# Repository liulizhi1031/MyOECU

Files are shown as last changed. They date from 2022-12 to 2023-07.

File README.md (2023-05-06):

# 开源嵌入式计算单元

**MyO**pensource**E**mbedded**C**ompute**U**nit (**MyOECU**)

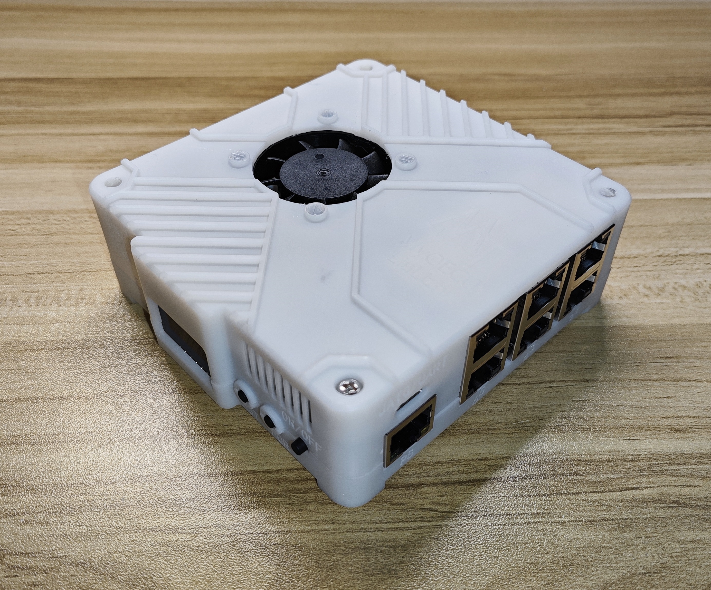
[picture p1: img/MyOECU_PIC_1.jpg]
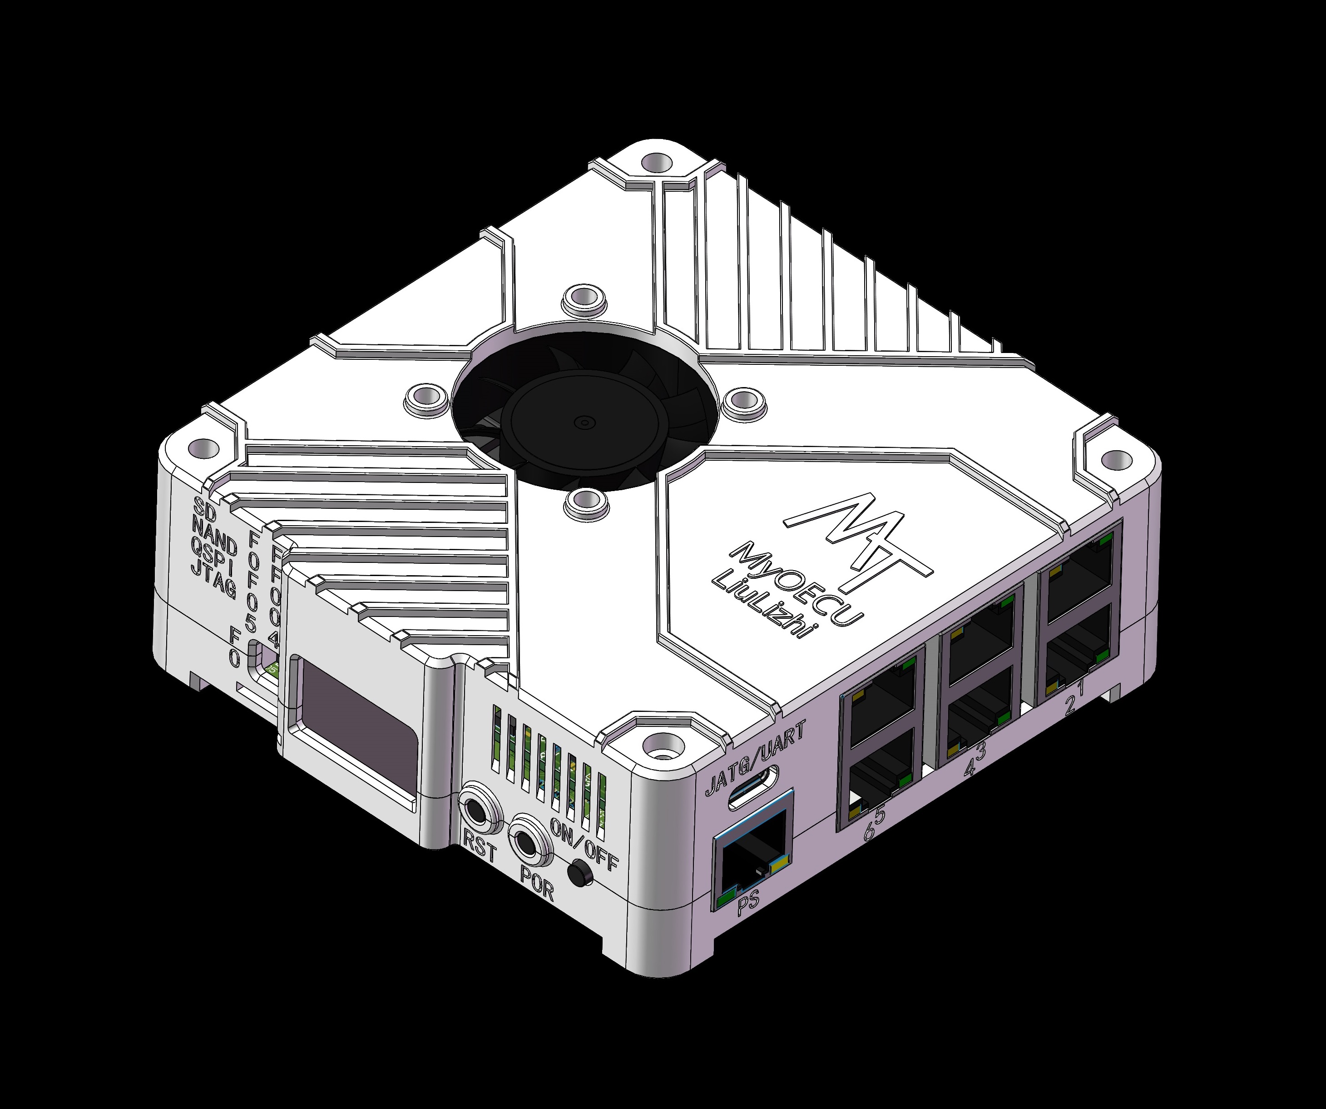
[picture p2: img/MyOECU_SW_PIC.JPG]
<div align="center">  

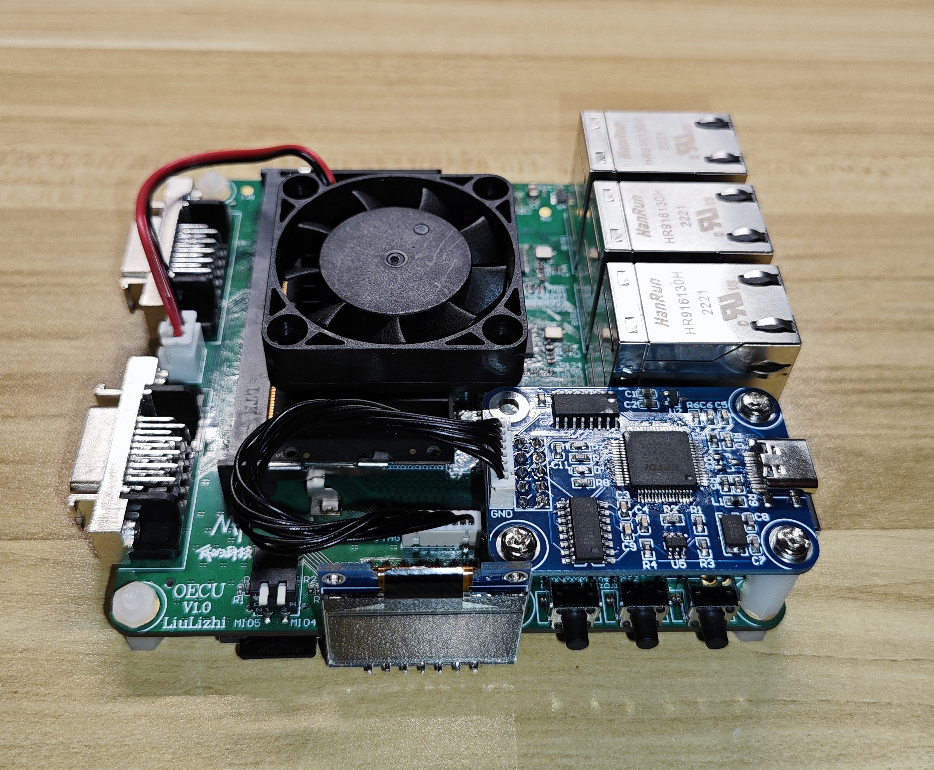
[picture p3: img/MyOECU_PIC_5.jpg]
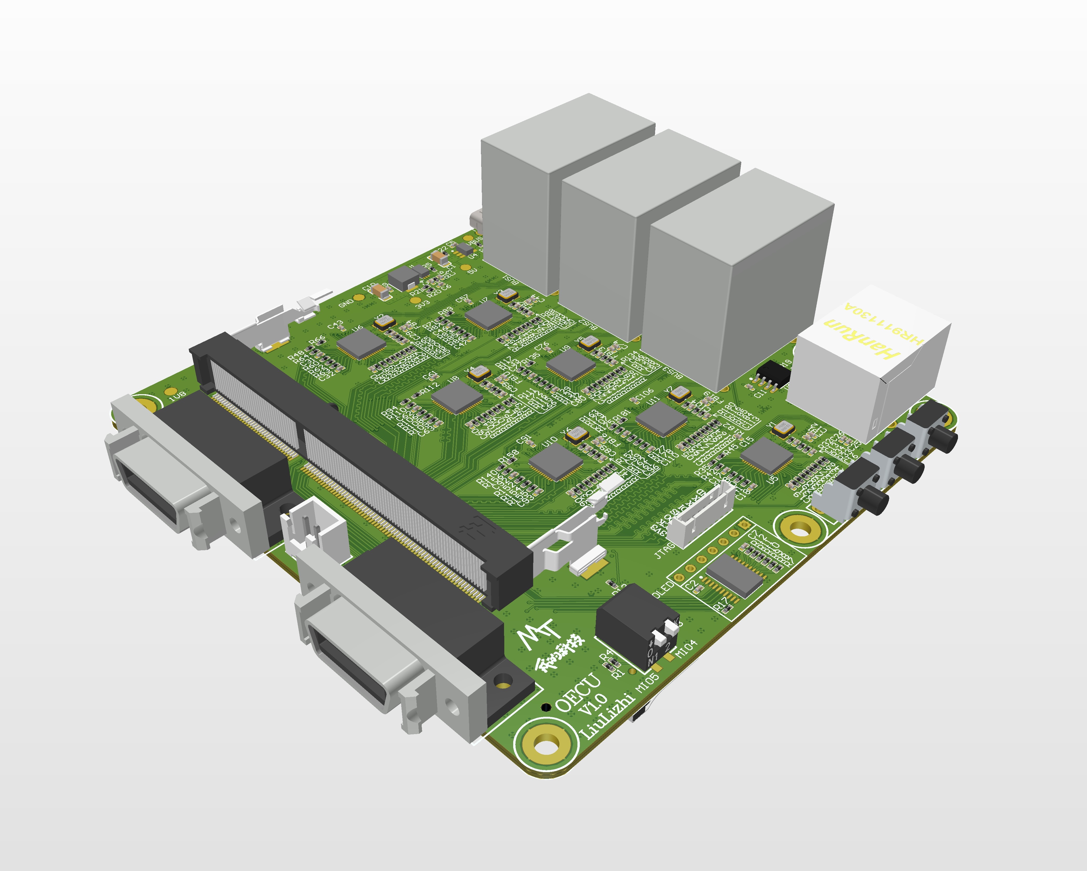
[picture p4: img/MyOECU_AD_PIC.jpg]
<div align="center"> 

<div align="left">

- ## 简介

	本项目是一种开源嵌入式计算单元原型机，主要用于构建分布式控制系统，充当核心计算角色或小型总线交换机。通过板载的三路双冗余千兆网络总线，本计算单元可以方便的与其他计算单元、传感器、交换机、作动器等实现互联互操作。使用基于PreemptRT的实时Linux操作系统或FreeRTOS，可快速实现应用软件开发。本计算单元适用于航空航天、工业控制、智能家居等诸多领域。

- ## 组成

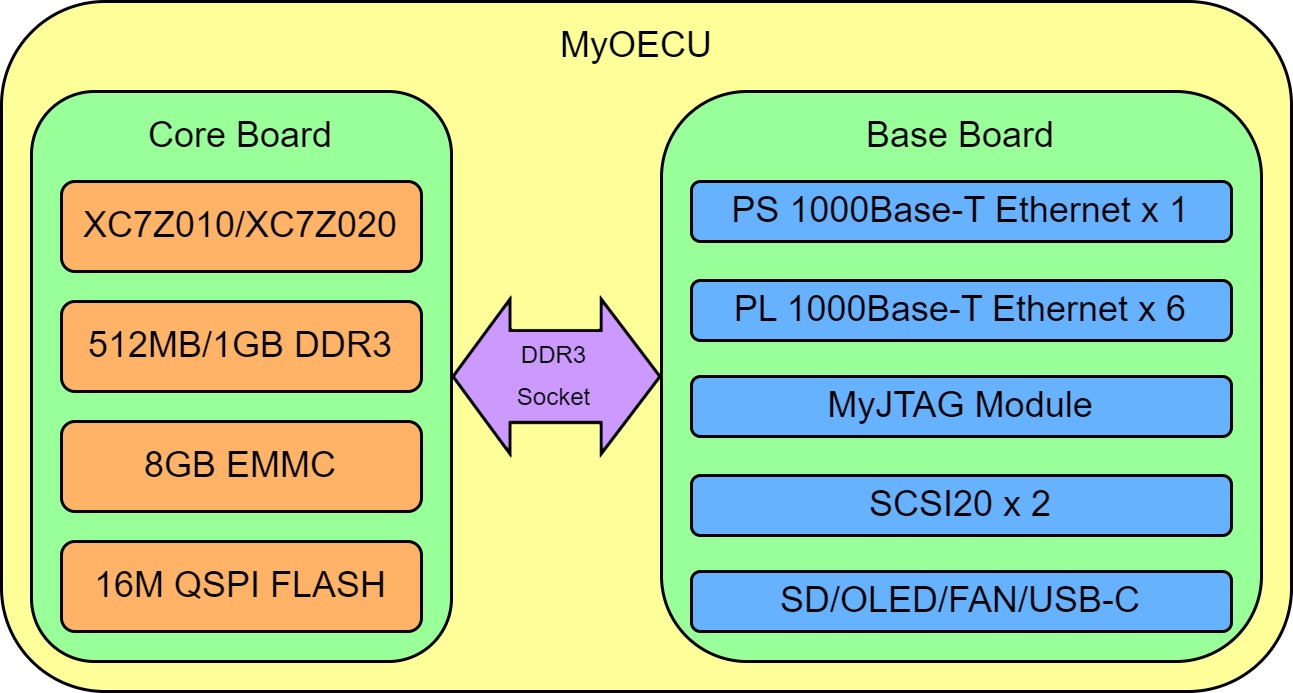
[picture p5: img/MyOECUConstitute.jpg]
MyOECUConstitute


1. 使用Zynq7010/7020作为主控制器，核心板通过DDR3插槽与底板相连；
2. 一路PS端千兆以太网接口；
3. 六路PL端千兆以太网接口，搭配FPGA软件组成三组双冗余高速总线或六组高速总线；
4. 预留MyJTAG模块接口，包含一路JTAG调试接口与一路串口，共用一个USB Type-C接口与调试机相连；
5. 主电源接口为USB Type-C接口，支持5V 3A输入，除此之外也可使用SCSI20扩展接口供电。主电源开关由负载开关组成，一键开关机；
6. 预留CAN总线接口、串口等IO资源，通过SCSI20接口与外部相连，预留SD卡接口，搭载0.96寸SPI接口OLED显示屏；
7. PCB尺寸为10cm*10cm，六层板；

- ## 分布式控制系统

分布式控制系统相比集中式控制系统拥有较多优势：

1. 采用模块化设计，方便对子模块进行快速调试、维护、更换、升级等操作
2. 更好的故障隔离能力，对于设计良好的分布式系统，部分子模块损坏并不会影响整个控制网络的基本运行
3. 可灵活进行系统的余度配置，有利于提高系统的可靠性
4. 通用设计的计算单元可快速构建不同功能模块，降低系统研发成本，加快系统研发进度
5. 单个功能模块功耗较低，有利于系统的热设计
6. 各功能模块分散布置，从而避免因局部机械失效导致的灾难性后果

- ## 应用示例

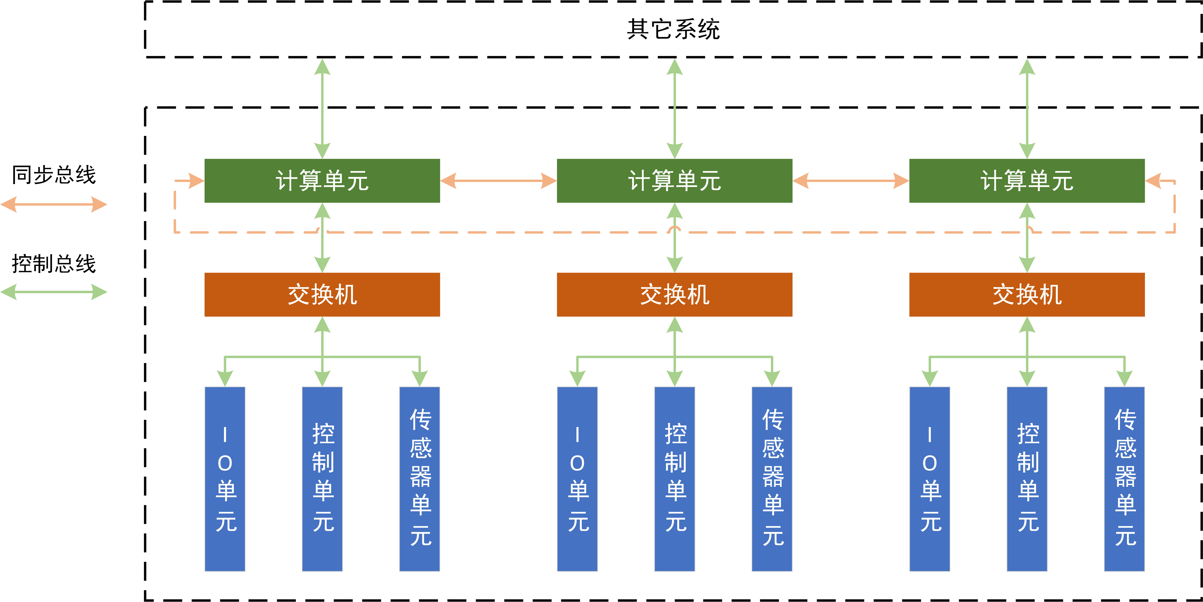
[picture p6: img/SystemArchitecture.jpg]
SystemArchitecture


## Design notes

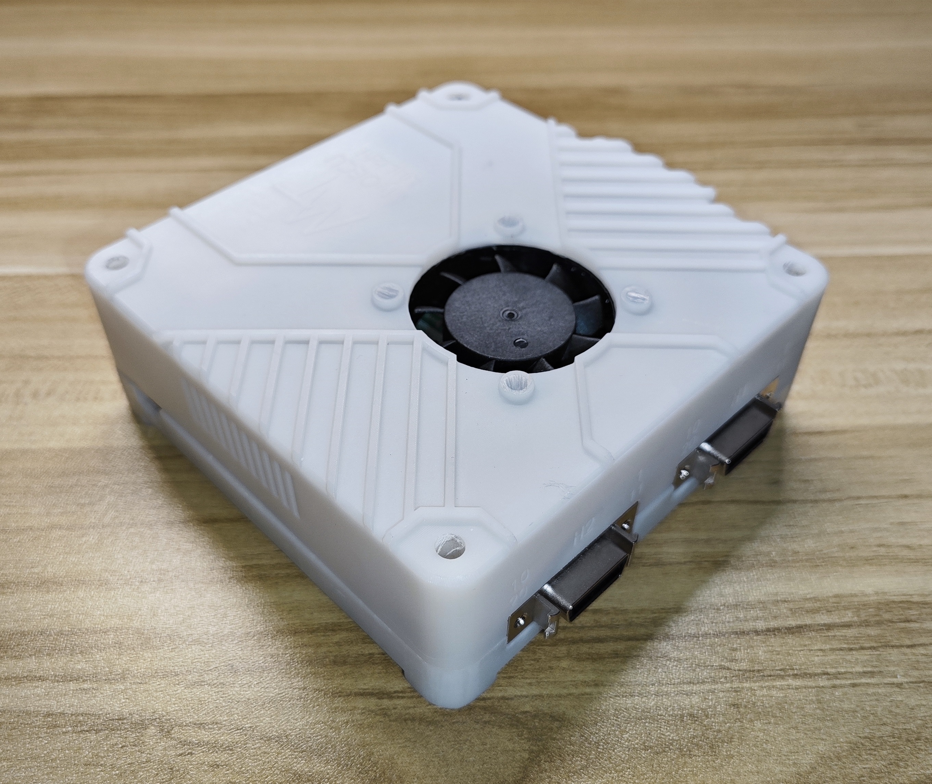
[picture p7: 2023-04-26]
img/MyOECU_PIC_3.jpg

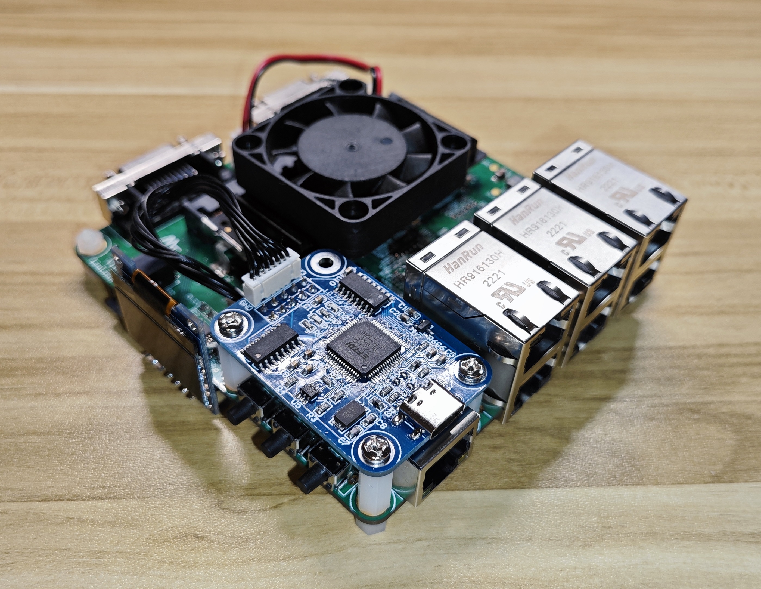
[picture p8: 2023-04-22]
img/MyOECU_PIC_4.jpg

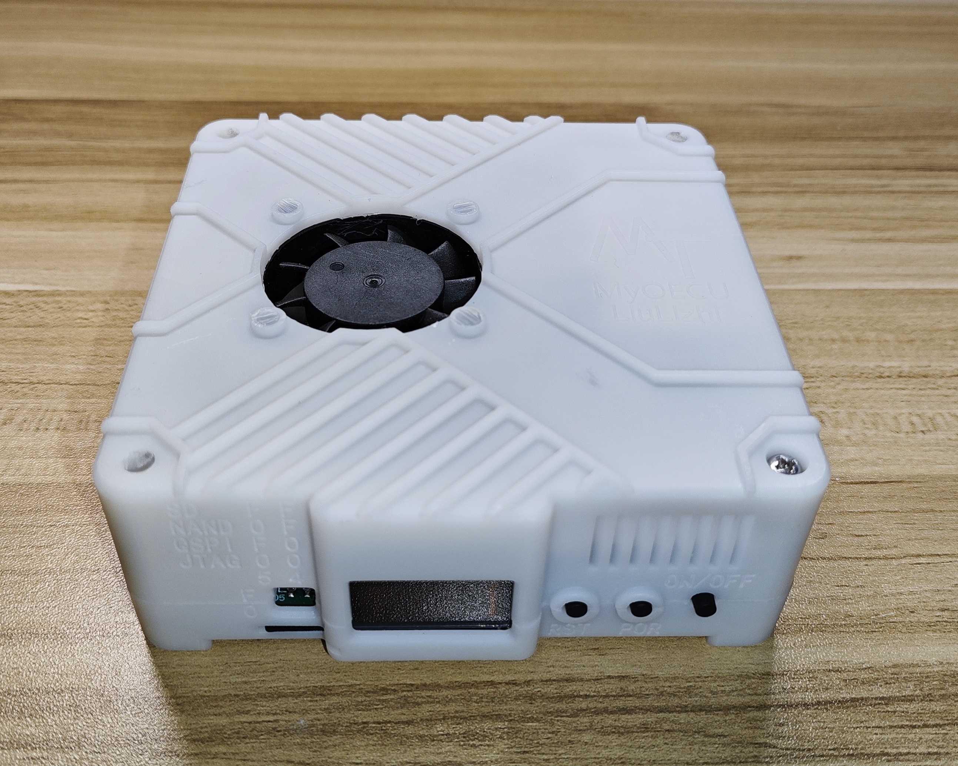
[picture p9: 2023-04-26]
img/MyOECU_PIC_2.jpg

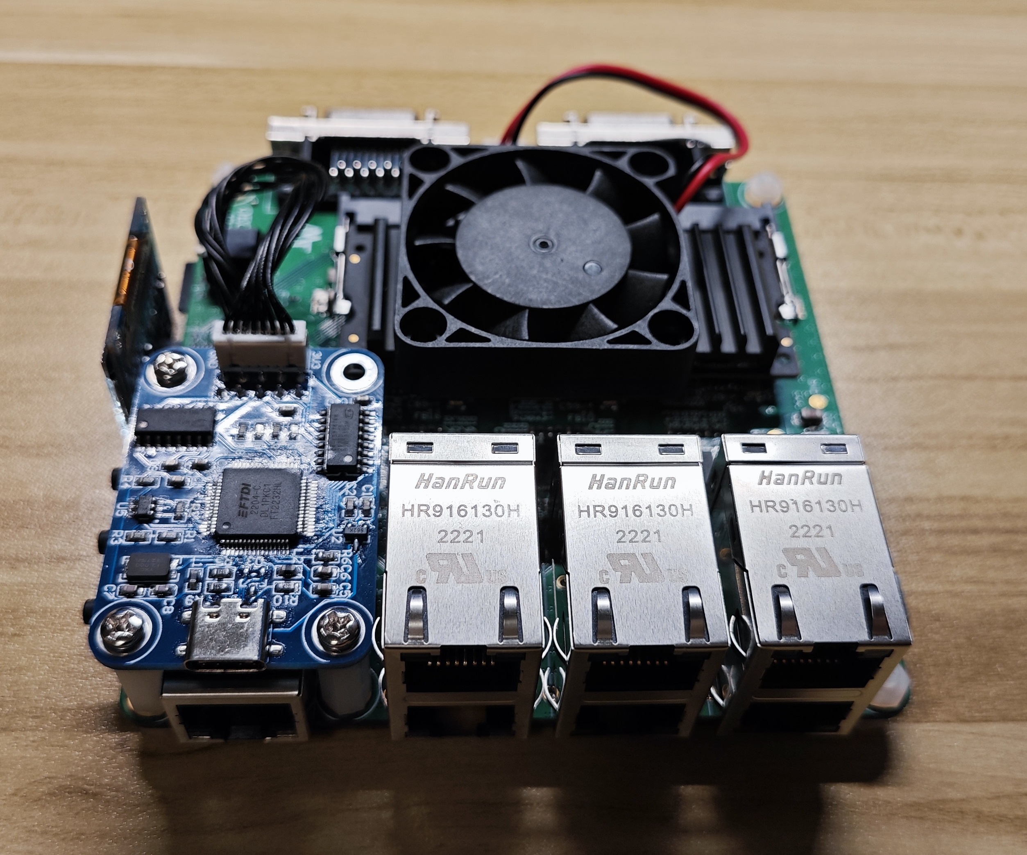
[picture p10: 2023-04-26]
img/MyOECU_PIC_6.jpg

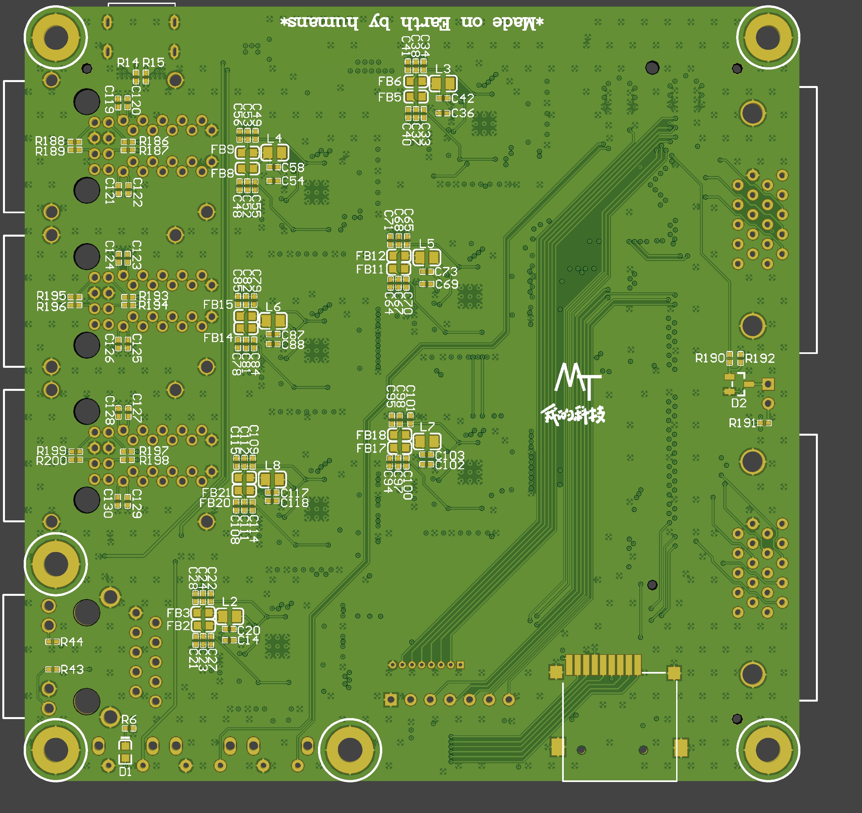
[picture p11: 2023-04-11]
3D_model/MyOECU/OECU_BASE_BUTTOM.jpg

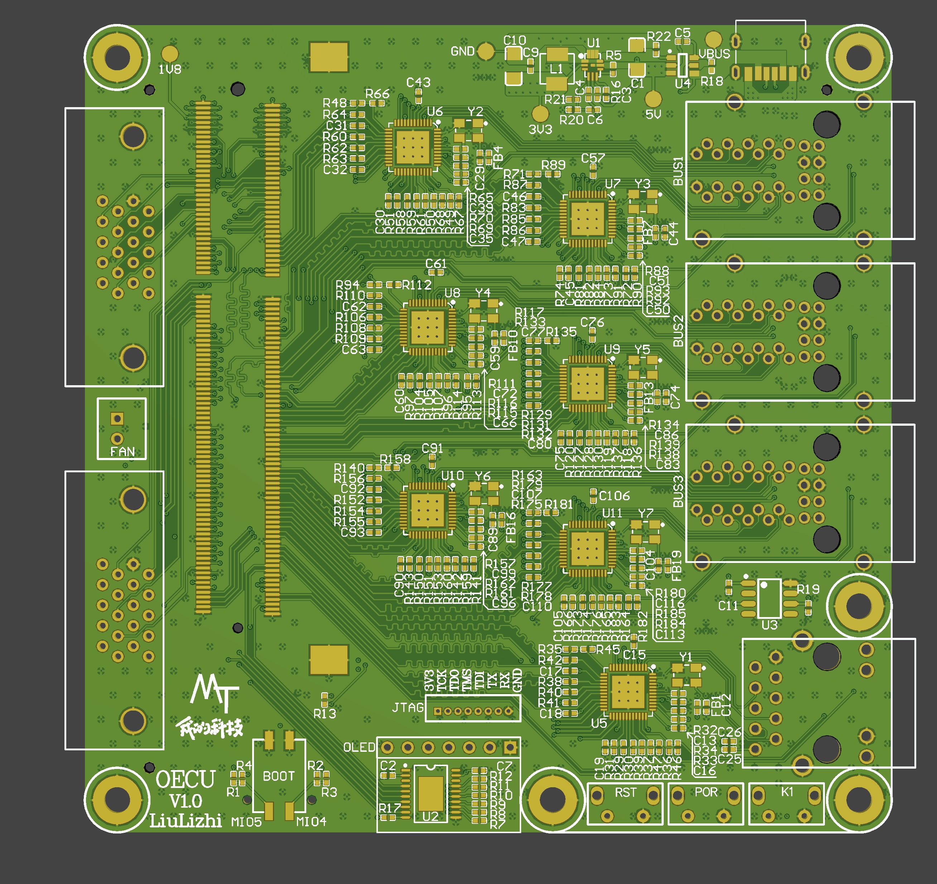
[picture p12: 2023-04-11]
3D_model/MyOECU/OECU_BASE_TOP.jpg

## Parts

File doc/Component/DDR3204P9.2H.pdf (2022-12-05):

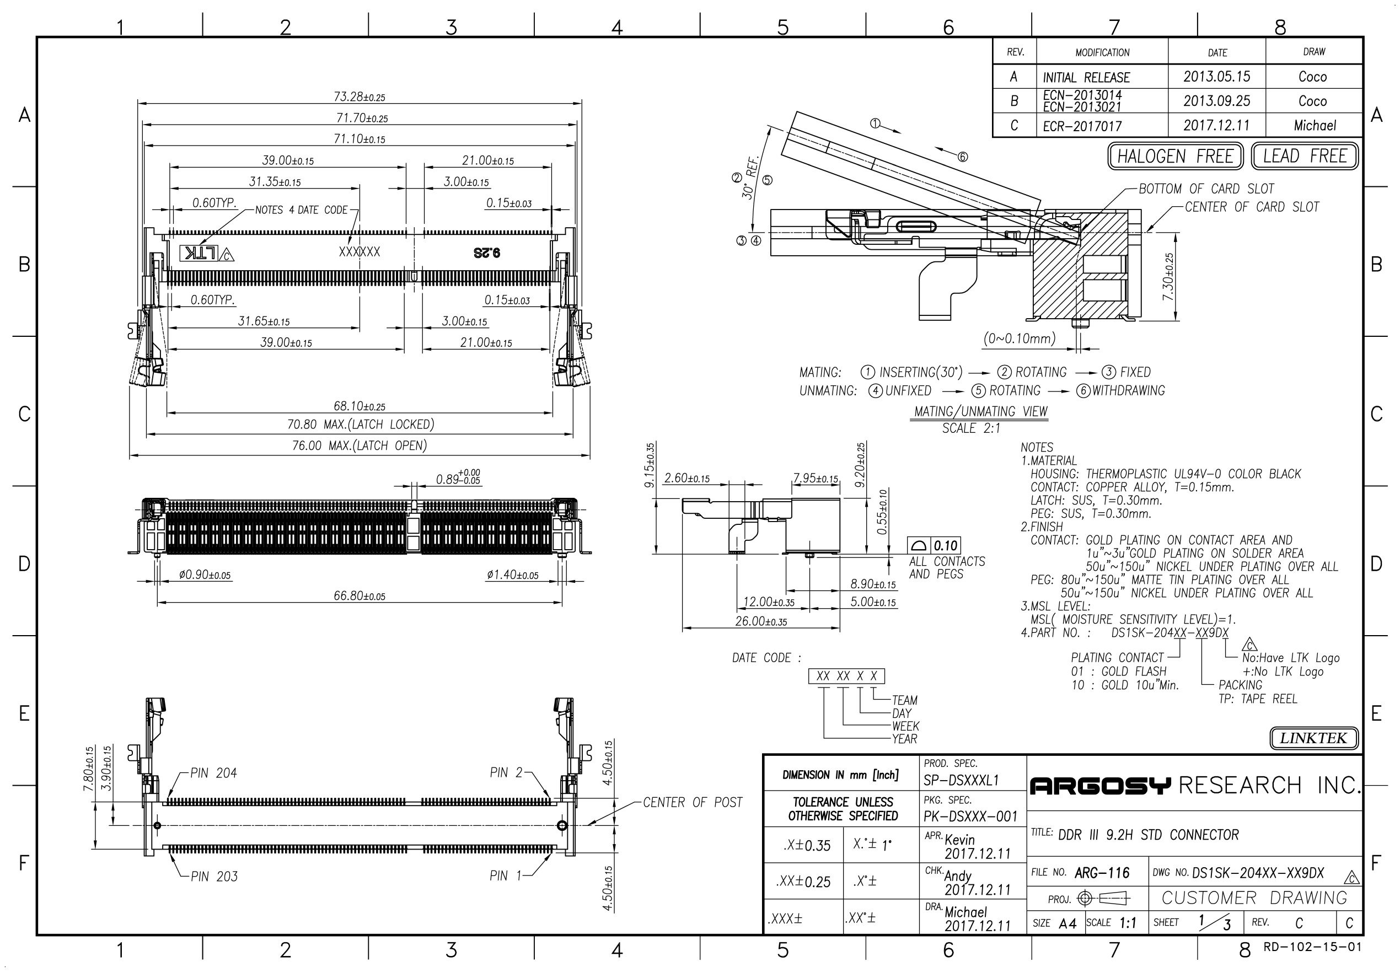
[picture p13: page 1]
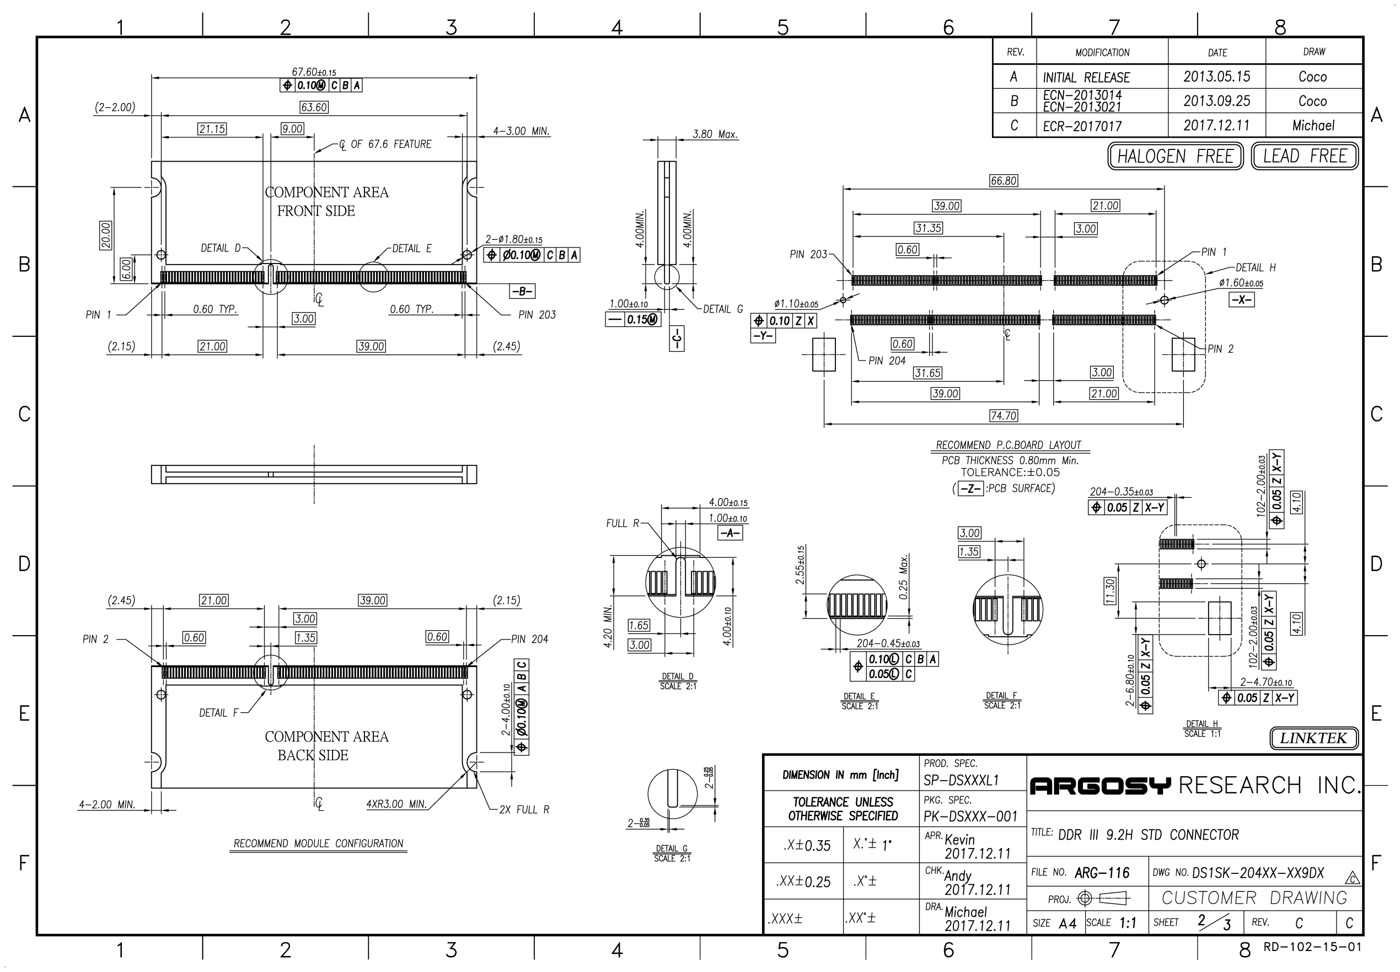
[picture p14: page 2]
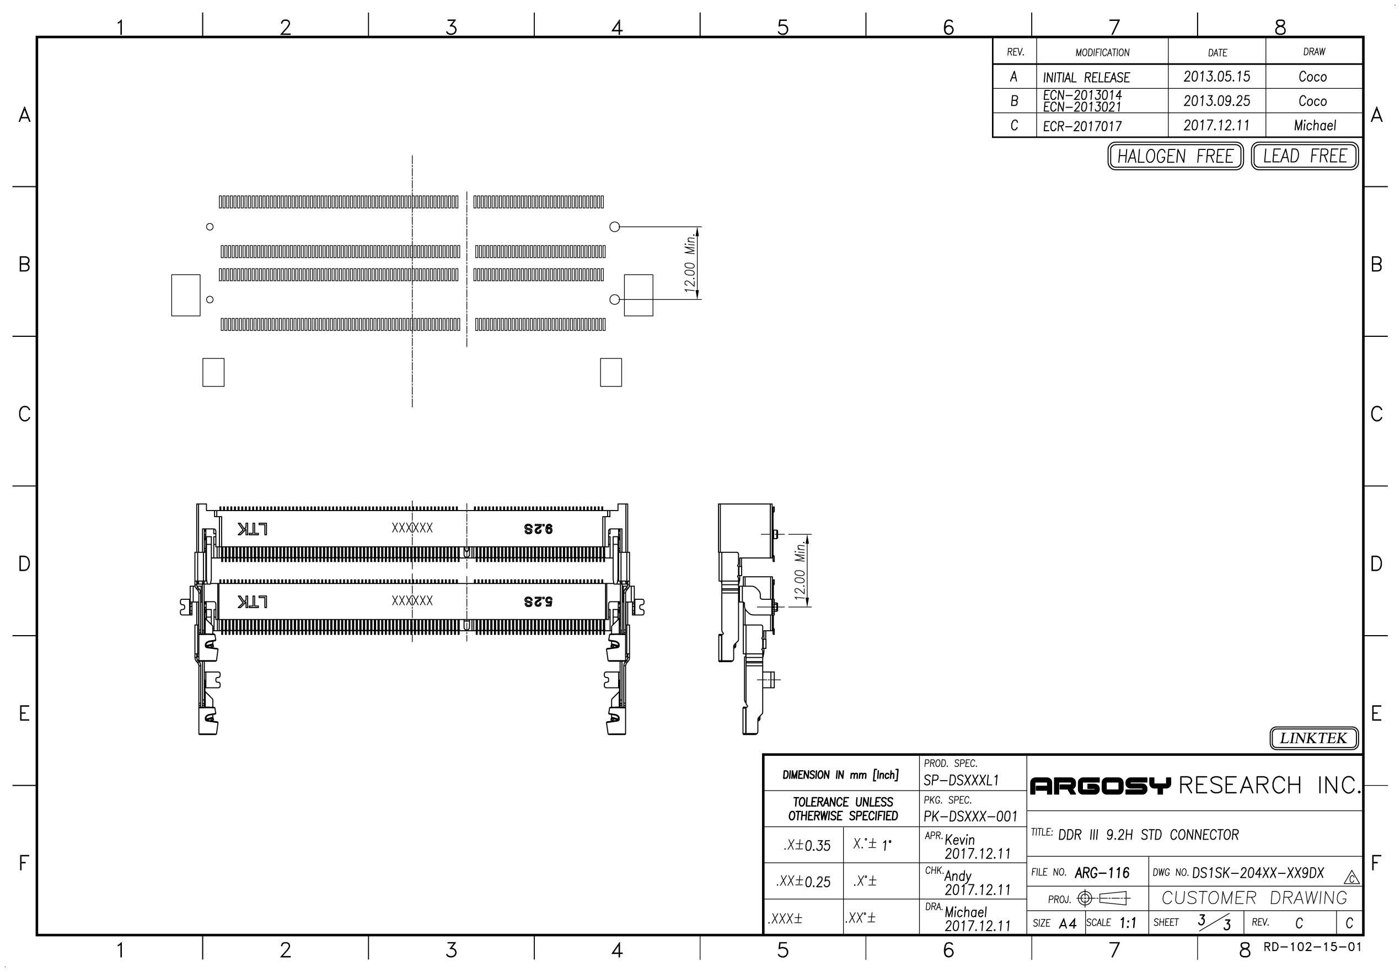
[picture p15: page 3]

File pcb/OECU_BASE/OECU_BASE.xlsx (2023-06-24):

Designator | Comment | Quantity | LibRef | Layer | Description | Footprint
1V8, 3V3, 5V, GND, VBUS | TEST_POINT_2mm | 5 | TEST_POINT_2mm | Top |  | TEST_POINT_2mm
BOOT | DIP_SWITCH_2.54_2_SMD_S | 1 | DIP_SWITCH_2.54_2_SMD_S | Top | 双路贴片立式拨码开关 | DIP_SWITCH_2.54_2_SMD_S
BUS1, BUS2, BUS3 | RJ45_HR916130H | 3 | RJ45_HR916130H | Top |  | HR916130H
C1, C10 | 22uF | 2 | CAP_1206 | Top | 贴片电容 1206 | 1206
C2, C3, C4, C5, C6, C7, C9, C11, C12, C13, C15, C16, C17, C18, C25, C29, C31, C32, C35, C44, C46, C47, C50, C51, C59, C61, C62, C63, C66, C74, C76, C77, C80, C83, C89, C91, C92, C93, C96, C104, C106, C107, C110, C113 | 104 | 44 | CAP_0402 | Top | 贴片电容 0402 | 0402
C19, C26, C30, C39, C43, C45, C57, C60, C72, C75, C86, C90, C99, C105, C116 | 10uF | 15 | CAP_0402 | Top | 贴片电容 0402 | 0402
FAN | XH2.54_2P | 1 | XH2.54_2P | Top |  | XH2.5_2P
FB1, FB4, FB7, FB10, FB13, FB16, FB19 | 102 | 7 | FB_0402 | Top | 磁珠 0402 | 0402
H1, H2 | SCSI20_1 | 2 | SCSI20_1 | Top |  | SCSI20_1
JTAG | SH1.25mm_8P | 1 | SH1.25mm_8P | Top |  | SH1.25MM_8P
K1, POR, RST | KEY | 3 | KEY_DIP_6_L | Top | 直插卧式按键 6mm | KEY_DIP_6_L
L1 | 3.3uH | 1 | L_0420 | Top | 电感 0420 | L_0420
M1 | DDR3_204P_H8 | 1 | DDR3_204P_H8 | Top |  | DDR3_204P_H8
OLED | Header_2.54_7P | 1 | Header_2.54_7P | Top |  | HDR1_7P
P1 | RJ45 | 1 | RJ45_HR911130A | Top |  | HR911130A
R1, R2 | 20K | 2 | RES_0402 | Top | 电阻 0402 | R_0402
R3, R4, R7, R8, R9, R10, R11, R12, R13, R18, R19, R31, R51, R74, R97, R120, R143, R166 | 10K | 18 | RES_0402 | Top | 电阻 0402 | R_0402
R5, R16, R17, R37, R38, R39, R40, R41, R42, R45, R46, R50, R60, R61, R62, R63, R64, R66, R67, R73, R83, R84, R85, R86, R87, R89, R90, R96, R106, R107, R108, R109, R110, R112, R113, R119, R129, R130, R131, R132, R133, R135, R136, R142, R152, R153, R154, R155, R156, R158, R159, R165, R175, R176, R177, R178, R179, R181, R182 | 4K7 | 59 | RES_0402 | Top | 电阻 0402 | R_0402
R20 | 44K2 | 1 | RES_0402 | Top | 电阻 0402 | R_0402
R21 | 200K | 1 | RES_0402 | Top | 电阻 0402 | R_0402
R22 | 1K | 1 | RES_0402 | Top | 电阻 0402 | R_0402
R29, R30, R58, R59, R81, R82, R104, R105, R127, R128, R150, R151, R173, R174 | 1K5 | 14 | RES_0402 | Top | 电阻 0402 | R_0402
R32, R65, R88, R111, R134, R157, R180 | 22R | 7 | RES_0402 | Top | 电阻 0402 | R_0402
R33, R69, R92, R115, R138, R161, R184 | 0R | 7 | RES_0402 | Top | 电阻 0402 | R_0402
R34, R70, R93, R116, R139, R162, R185 | 2.49K | 7 | RES_0402 | Top | 电阻 0402 | R_0402
R35, R36, R47, R48, R49, R68, R71, R72, R91, R94, R95, R114, R117, R118, R137, R140, R141, R160, R163, R164, R183 | NC | 21 | RES_0402 | Top | 电阻 0402 | R_0402
U1 | MP2145 | 1 | MP2145 | Top | 5.5V, 6A, 1.2MHz | QFN12
U2 | TXS0108E | 1 | TXS0108E | Top |  | TSSOP20
U3 | EC191120 | 1 | EC191120 | Top | 长按2秒开关机 | SOP8-150MIL
U4 | TPS27081A | 1 | TPS27081A | Top | 高侧负载开关 | SOT_23_6
U5 | RTL8211E-VL | 1 | RTL8211E | Top | QFN48 | QFN48
U6, U7, U8, U9, U10, U11 | RTL8211E-VB | 6 | RTL8211E | Top | QFN48 | QFN48
USB1 | USB_C_6P | 1 | USB_C_6P | Top |  | USB_C_6PIN
Y1, Y2, Y3, Y4, Y5, Y6, Y7 | 25Mhz | 7 | XTAL_3225 | Top | 贴片有源晶振, [NoValue] | XTAL_3225
C14, C21, C22, C23, C24, C33, C34, C36, C37, C38, C48, C49, C52, C53, C64, C65, C67, C68, C78, C79, C81, C82, C94, C95, C97, C98, C108, C109, C111, C112, C119, C121, C123, C125, C127, C129 | 104 | 36 | CAP_0402 | Bottom | 贴片电容 0402 | 0402
C20, C27, C28, C40, C41, C42, C54, C55, C56, C58, C69, C70, C71, C73, C84, C85, C87, C88, C100, C101, C102, C103, C114, C115, C117, C118, C120, C122, C124, C126, C128, C130 | 10uF | 32 | CAP_0402 | Bottom | 贴片电容 0402 | 0402
D1 | LED | 1 | LED_0603 | Bottom | LED 0603 | LED_0603
D2 | SI2302 | 1 | MOSN_SI2302_SOT23 | Bottom | NMOS | SOT23
FB2, FB3, FB5, FB6, FB8, FB9, FB11, FB12, FB14, FB15, FB17, FB18, FB20, FB21 | 102 | 14 | FB_0603 | Bottom | 磁珠 0603 | 0603
J1 | TF_Card | 1 | TF_Card | Bottom | TF卡座 | TF_card
L2, L3, L4, L5, L6, L7, L8 | 2.2uH | 7 | L_0805 | Bottom | 电感 0805 | 0805
R6 | 1K | 1 | RES_0402 | Bottom | 电阻 0402 | R_0402
R14, R15 | 5K1 | 2 | RES_0402 | Bottom | 电阻 0402 | R_0402
R43, R44, R186, R187, R188, R189, R193, R194, R195, R196, R197, R198, R199, R200 | 510R | 14 | RES_0402 | Bottom | 电阻 0402 | R_0402
R190 | 100R | 1 | RES_0402 | Bottom | 电阻 0402 | R_0402
R191 | 10R | 1 | RES_0402 | Bottom | 电阻 0402 | R_0402
R192 | 10K | 1 | RES_0402 | Bottom | 电阻 0402 | R_0402

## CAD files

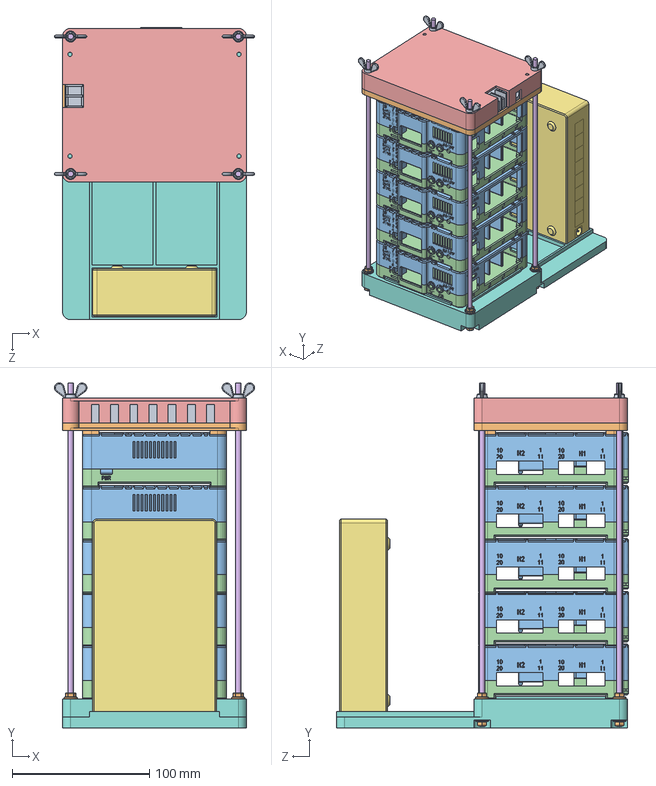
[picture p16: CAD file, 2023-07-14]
3D_model/ComputTower/配电模块装配.SLDASM
145.6 x 251.0 x 212.7 mm
配电模块
配电底壳
外壳_上壳 x 5
外壳_底壳 x 5
配电顶壳
丝杠M4_250 x 4
交换机
底座组件
WingNutM4 x 4
locknutM4 x 8

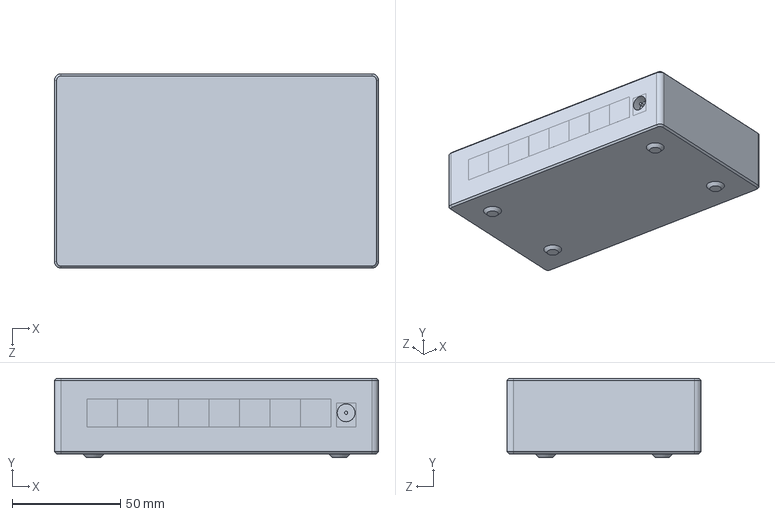
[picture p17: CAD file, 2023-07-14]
3D_model/ComputTower/交换机.SLDPRT
150.0 x 36.8 x 90.0 mm

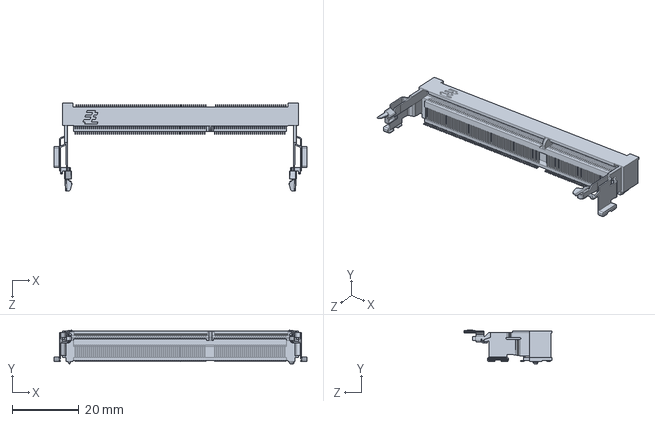
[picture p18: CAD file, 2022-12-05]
3D_model/DDR3_204P/DDR3_204P_H9.2.SLDPRT
76.0 x 10.1 x 26.6 mm

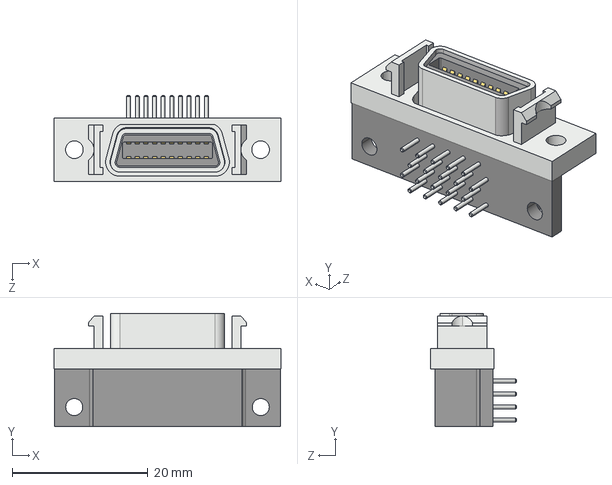
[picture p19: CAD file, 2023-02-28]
3D_model/SCSI-20/SCSI-20.STEP
33.4 x 16.7 x 12.6 mm

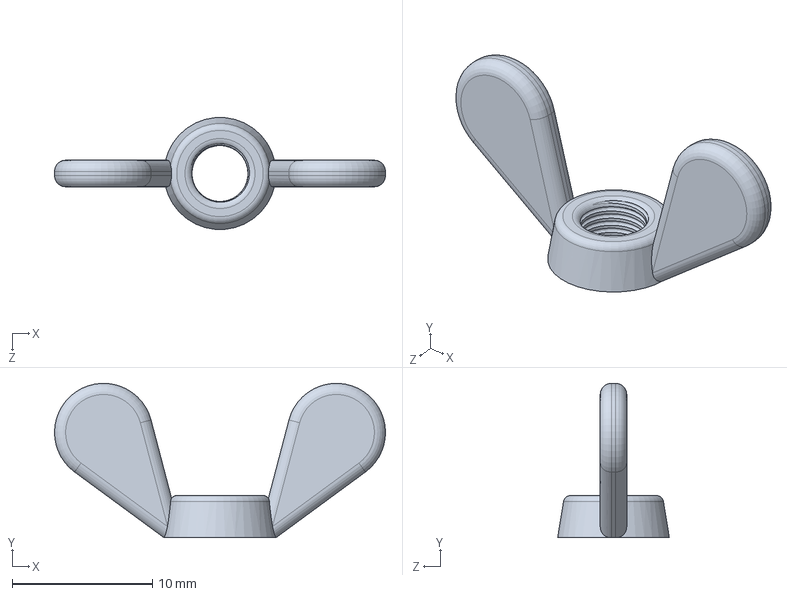
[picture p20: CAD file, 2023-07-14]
3D_model/WingNutM4.SLDPRT
23.6 x 11.0 x 7.97 mm

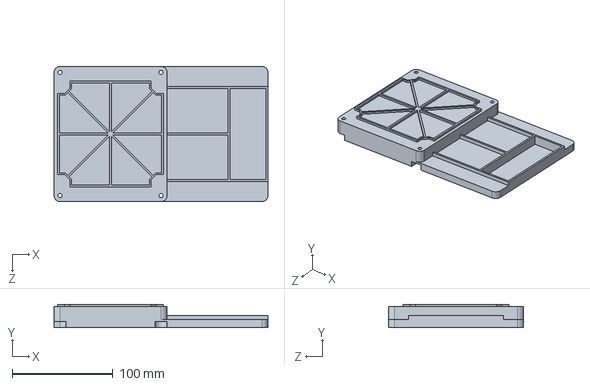
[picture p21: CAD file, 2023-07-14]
3D_model/ComputTower/底座组件.SLDPRT
212.0 x 23.0 x 134.0 mm

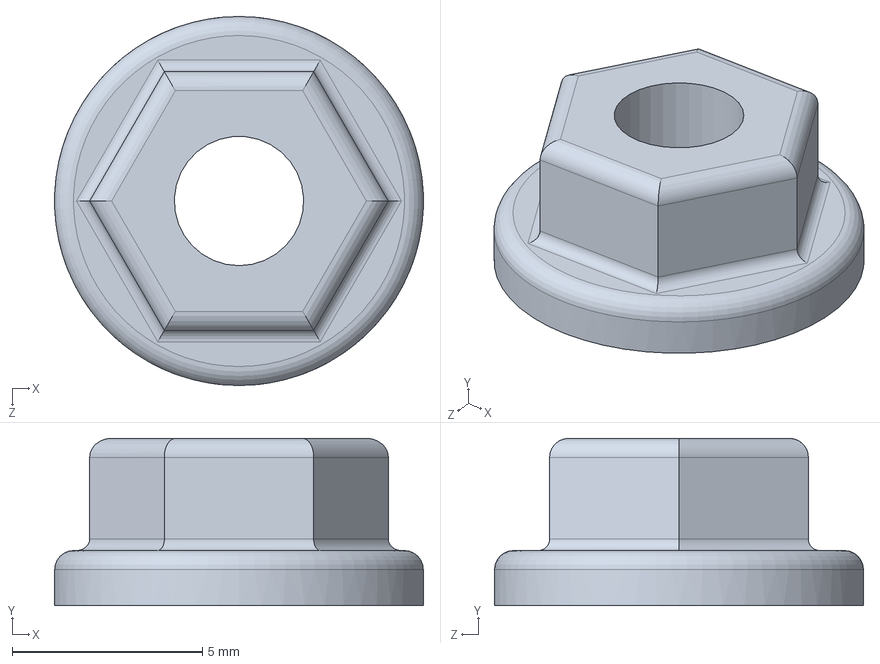
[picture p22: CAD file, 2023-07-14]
3D_model/locknutM4.SLDPRT
9.70 x 4.40 x 9.70 mm

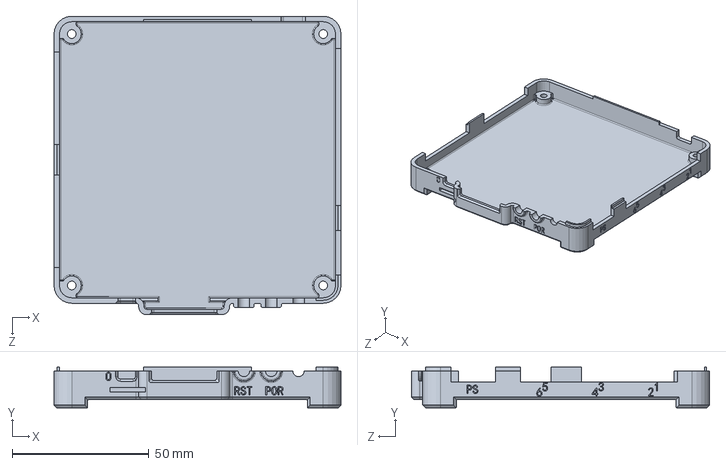
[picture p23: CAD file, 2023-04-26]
3D_model/外壳_底壳.SLDPRT
105.0 x 14.9 x 109.2 mm

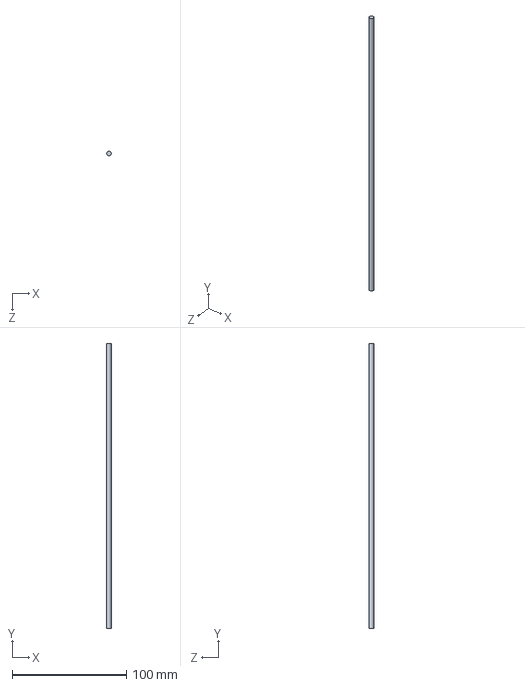
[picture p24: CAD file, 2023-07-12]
3D_model/ComputTower/丝杠M4_250.SLDPRT
4.00 x 250.0 x 4.00 mm

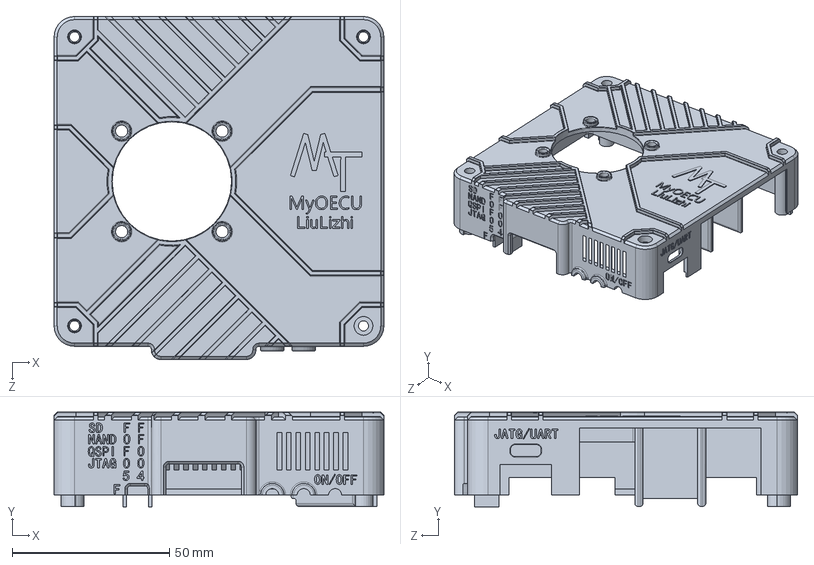
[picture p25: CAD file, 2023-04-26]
3D_model/外壳_上壳.SLDPRT
105.0 x 30.1 x 109.2 mm

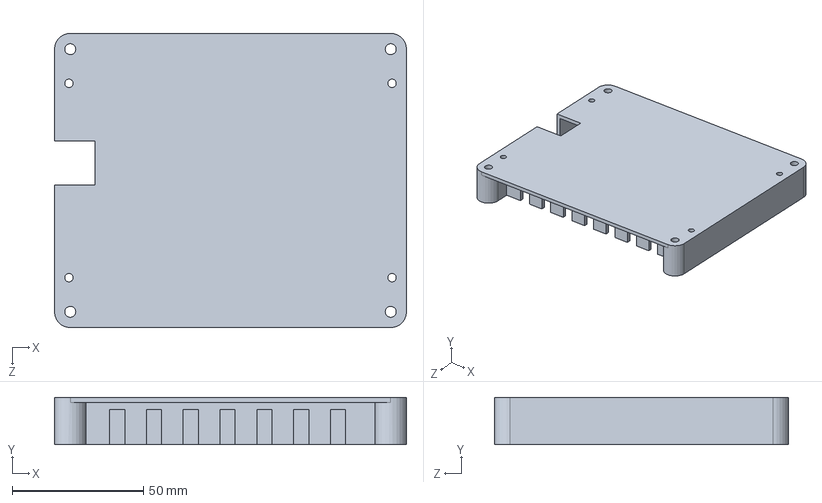
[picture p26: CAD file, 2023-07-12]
3D_model/ComputTower/配电顶壳.SLDPRT
134.0 x 18.0 x 112.0 mm

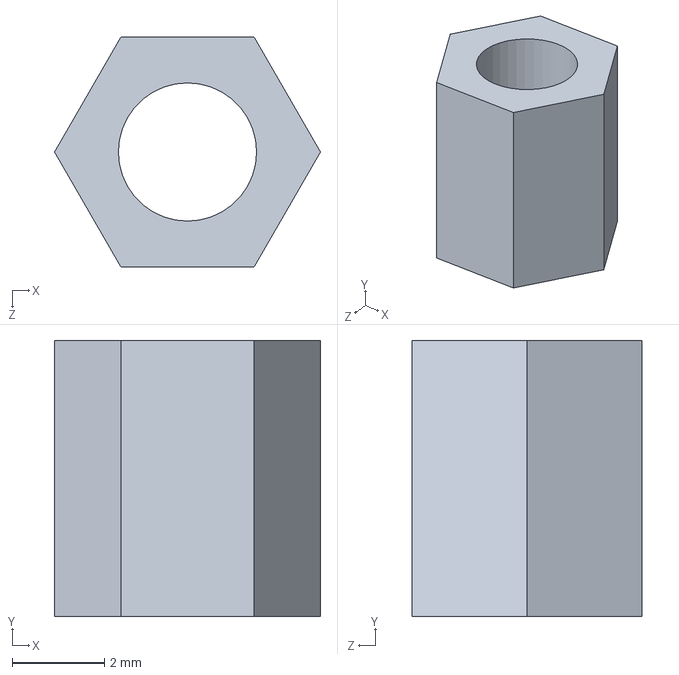
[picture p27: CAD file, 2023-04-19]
3D_model/Column_M3x6.SLDPRT
5.77 x 6.00 x 5.00 mm

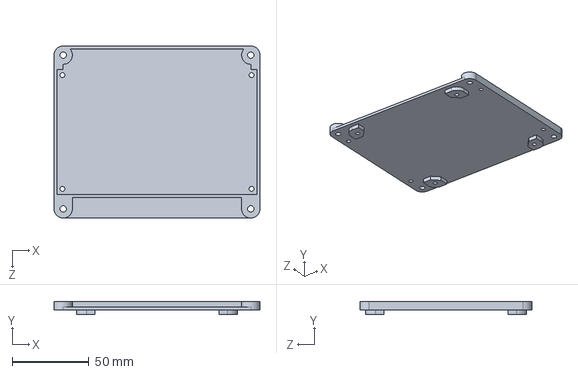
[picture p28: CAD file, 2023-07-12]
3D_model/ComputTower/配电底壳.SLDPRT
134.0 x 8.60 x 112.0 mm

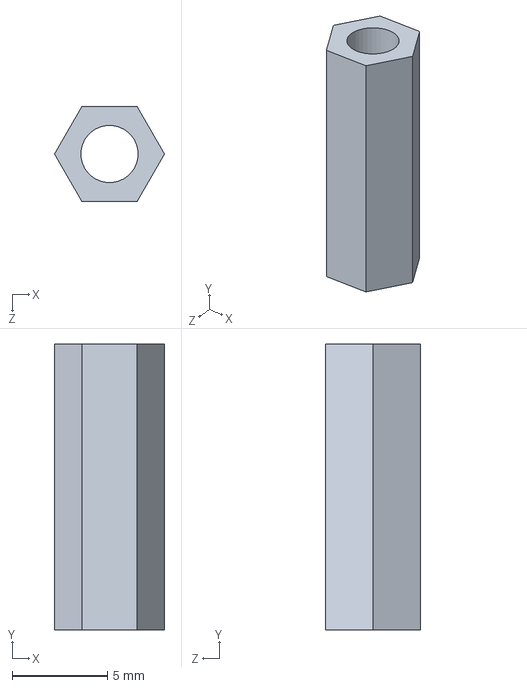
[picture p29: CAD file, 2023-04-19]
3D_model/Column_M3x16.SLDPRT
5.77 x 15.0 x 5.00 mm

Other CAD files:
3D_model/ComputTower/配电模块.SLDPRT
3D_model/OLED.SLDPRT
3D_model/PinSocket7_2.54.SLDPRT
3D_model/ZYNQ_CORE.SLDPRT
3D_model/Bolt_M3x6.SLDPRT
3D_model/HR916130H/HR916130.SLDPRT
3D_model/HR916130H/HR916130.STEP
3D_model/SCSI-20/SCSI-20.SLDPRT
3D_model/STL_FILE/外壳_上壳.STL
3D_model/STL_FILE/外壳_底壳.STL

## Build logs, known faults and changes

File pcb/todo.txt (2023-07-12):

1.微调元器件位置与间距，方便手动放置元器件；
2.针对SMT打样优化板子设计；
3.简化晶振电路；

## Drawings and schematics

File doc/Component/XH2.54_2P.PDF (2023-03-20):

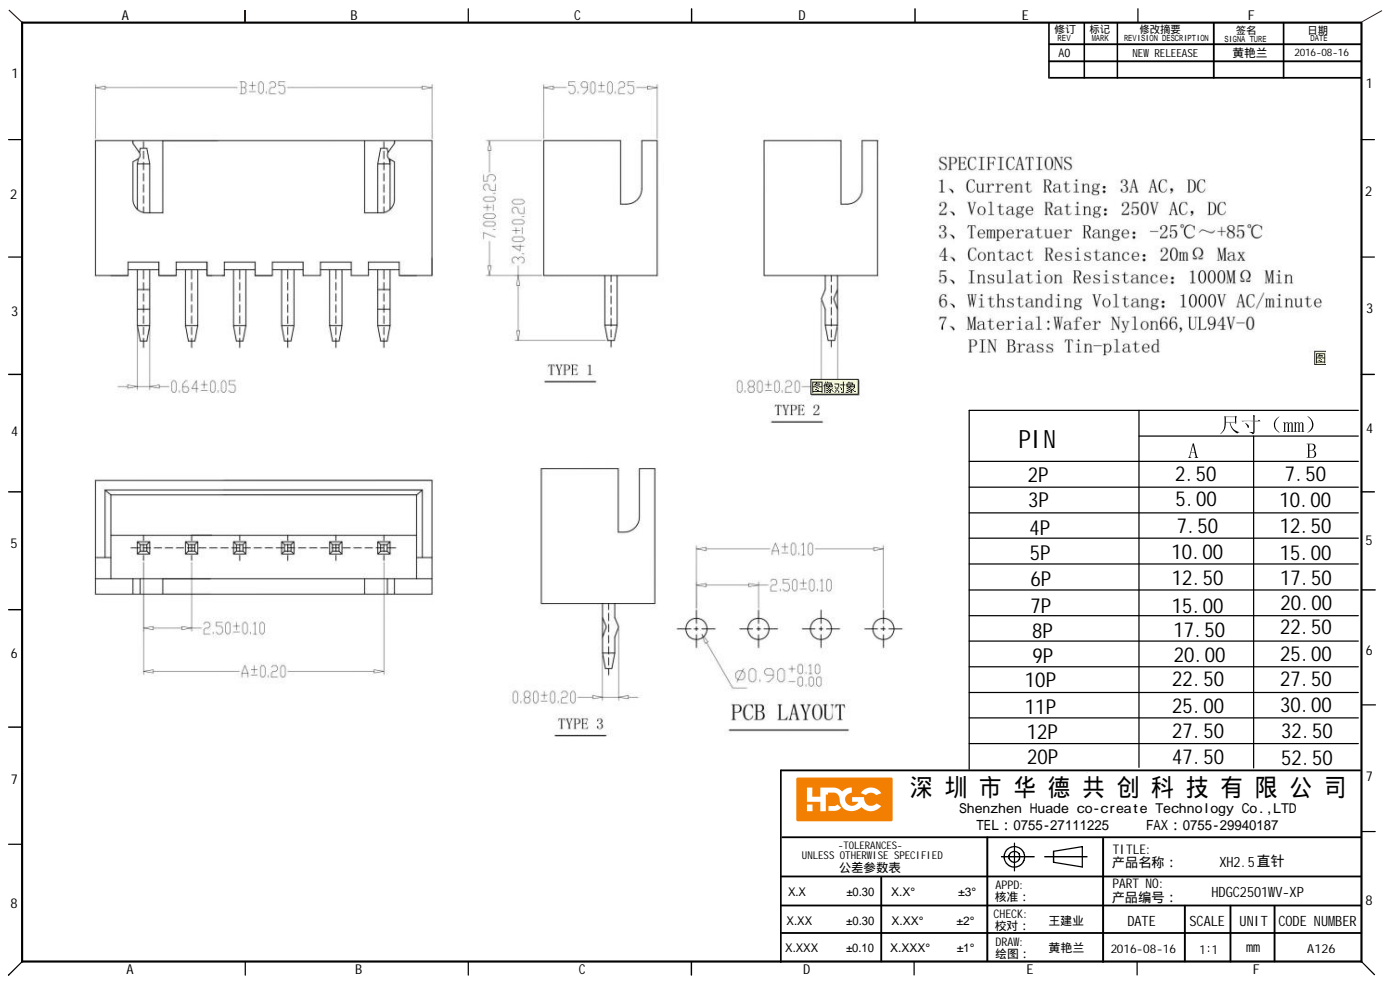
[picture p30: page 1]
修订 REV; 标记 MARK; 修改摘要 REVISION DESCRIPTION; SIGNA TURE; DATE; APPD: 核准： CHECK: 校对： DRAW: 绘图：; TITLE: 产品名称：; PART NO: 产品编号：; SCALE UNIT CODE NUMBER; -TOLERANCES-; 公差参数表; X.XXX; X.XXX°; NEW RELEEASE; 黄艳兰; 王建业; TEL：0755-27111225; FAX：0755-29940187; HDGC2501WV-XP; PIN

深 圳 市 华 德 共 创 科 技 有 限 公 司 Shenzhen Huade co-create Technology Co.,LTD

UNLESS OTHERWISE SPECIFIED

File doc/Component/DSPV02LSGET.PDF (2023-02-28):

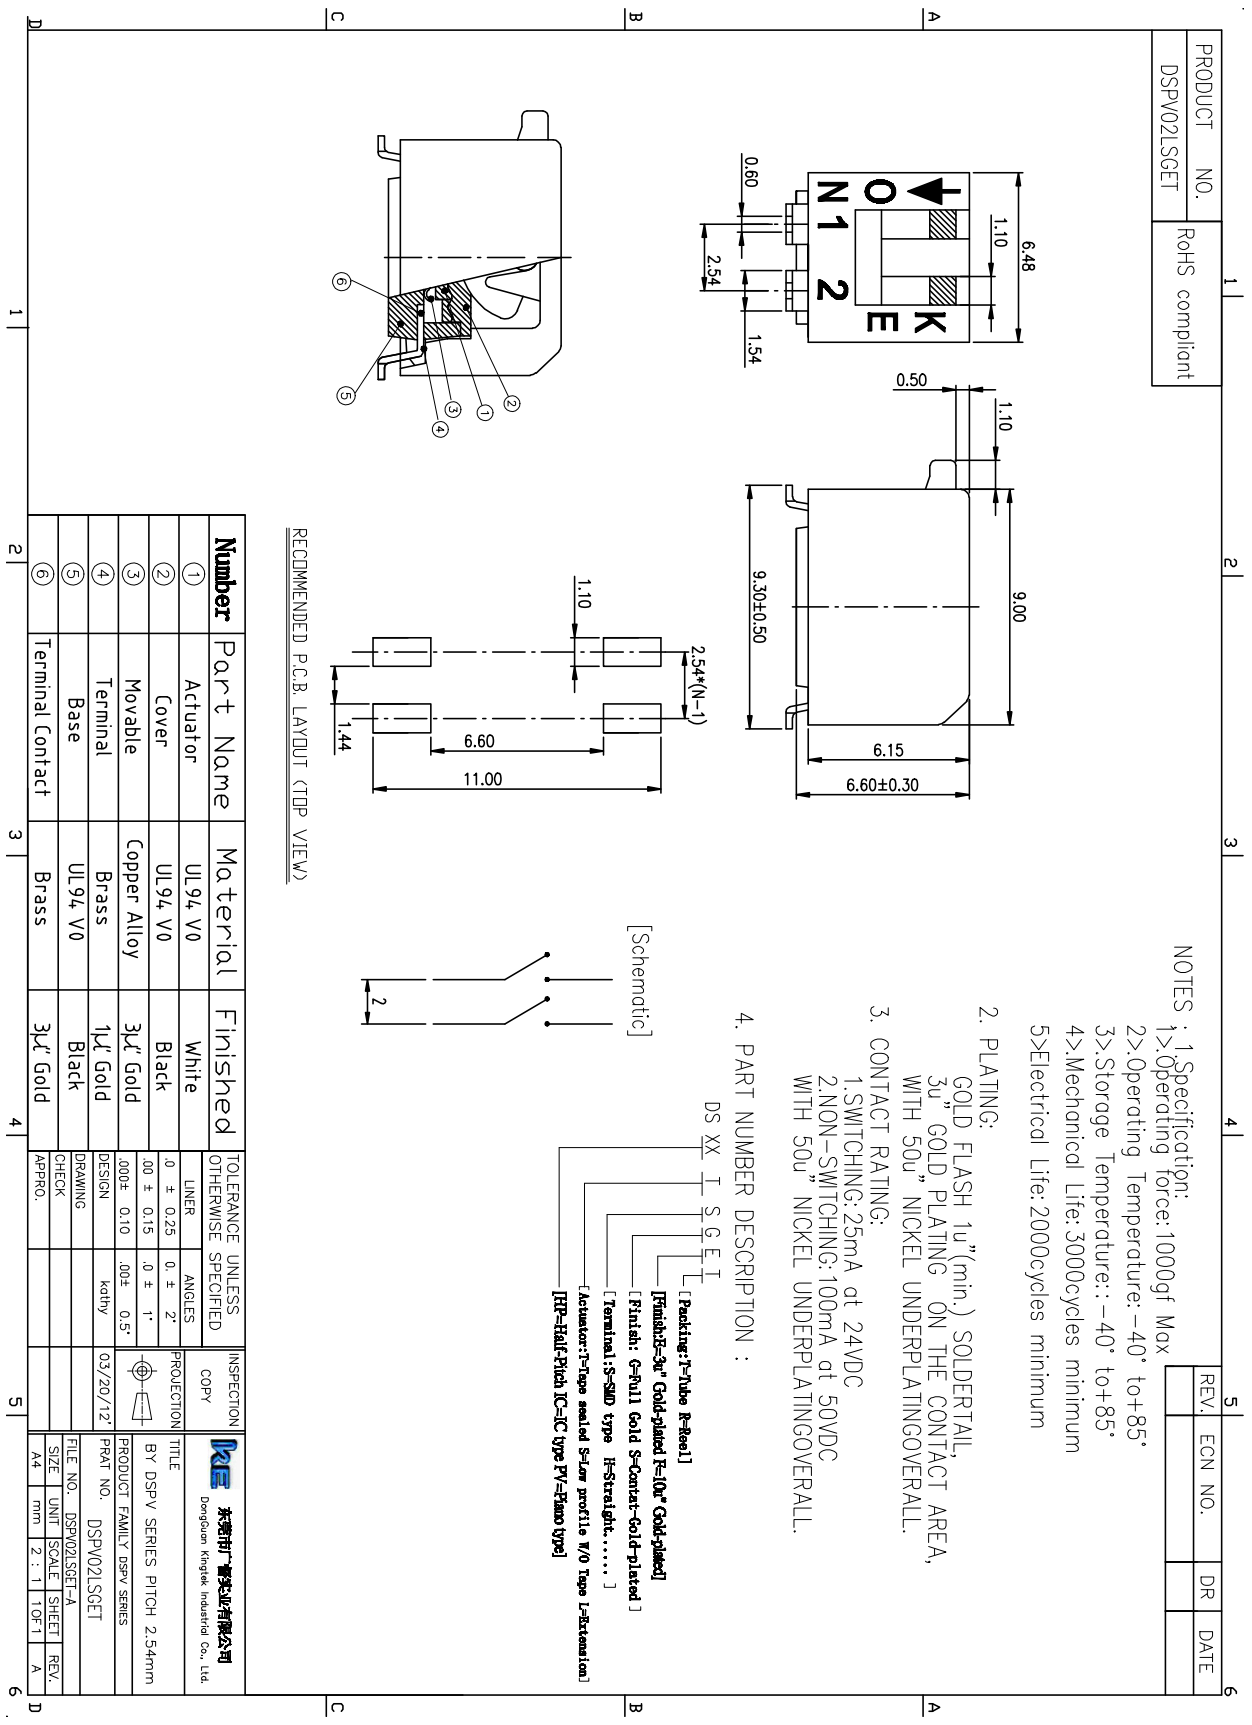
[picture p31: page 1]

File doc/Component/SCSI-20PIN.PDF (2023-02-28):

# HSF

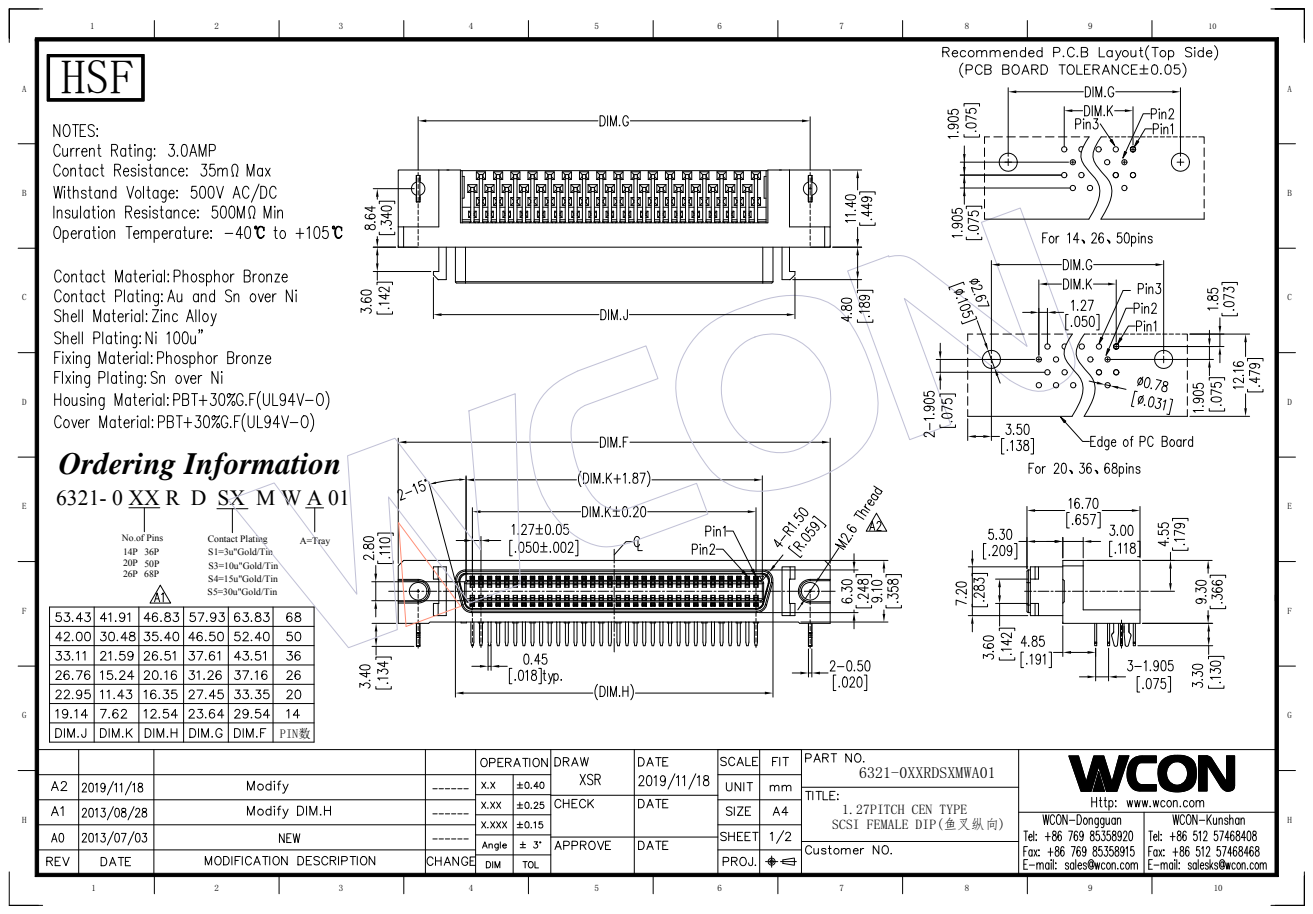
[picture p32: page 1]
6321-0XXRDSXMWA01; Ordering Information; Contact Plating; S5=30u"Gold/Tin; S4=15u"Gold/Tin; S3=10u"Gold/Tin; S1=3u"Gold/Tin; No.of Pins 14P; PIN数; A=Tray

1.27PITCH CEN TYPE
SCSI FEMALE DIP(鱼叉纵向)

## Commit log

2022-12-05 first time public project
    first update
    [DDR3_204P_H9.2.SLDPRT, OECU_BASE.PrjPcb, OECU_BASE1.SchDoc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]
2022-12-06 更改板子外形
    1.板子外形修改为13*13
    2.增加PL端拓展接口
    [OECU_BASE.PrjPcb, OECU_BASE1.SchDoc, OECU_BASE2.SchDoc]
2022-12-07 PCB update
    PCB update
    [OECU_BASE.PrjPcb, OECU_BASE2.SchDoc, OECU_BASE3.SchDoc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]
2022-12-09 20221210
    20221210
    [OECU_BASE2.SchDoc]
2022-12-11 20221211
    20221211
    [OECU_BASE.PrjPcb, OECU_BASE1.SchDoc]
2022-12-15 20221216
    20221216
    [OECU_BASE.PrjPcb, OECU_BASE1.SchDoc, OECU_BASE3.SchDoc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]
2022-12-20 20221221
    PCB CHANGE
    [OECU_BASE.PrjPcb, OECU_BASE1.SchDoc]
2022-12-22 20221222
    20221222
    [OECU_BASE2.SchDoc]
2022-12-25 2022122501
    2022122501
    [OECU_BASE.PrjPcb, OECU_BASE1.SchDoc]
2022-12-25 2022122502
    2022122502
    [OECU_BASE.PrjPcb, OECU_BASE_BOM.xlsx]
2022-12-26 20221227
    20221227
    [OECU_BASE2.SchDoc, OECU_BASE3.SchDoc, OECU_BASE4.SchDoc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]
2022-12-27 PCB basic design complete
    basic design complete
    [OECU_BASE.PrjPcb, OECU_BASE1.SchDoc, OECU_BASE2.SchDoc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]
2022-12-28 20221228
    change via to 0.45mm
    [OECU_BASE.PrjPcb]
2022-12-28 20221229
    update 3d model
    [Bolt_M3x6.SLDPRT, Column_M3x11.SLDPRT, ZYNQ_CORE.SLDPRT]
2022-12-29 20221229
    修复阻焊层盖油问题
    [OECU_BASE.PrjPcb]
2023-01-10 20230110
    20230110
    [OECU_BASE_BOM.xlsx]
2023-02-28 20230228
    V1.0版本PCB设计初入库
    [DDR3_204P_H9.2.SLDPRT, HR916130.SLDPRT, HR916130.STEP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]
2023-03-09 PCB change
    pcb change
    [OECU_BASE1.SchDoc, OECU_BASE2.SchDoc]
2023-03-10 refactor: PCB change
    PCB change
    [OECU_BASE1.SchDoc, OECU_BASE2.SchDoc, OECU_BASE3.SchDoc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]
2023-03-12 refactor: PCB design update
    PCB design update
    [OECU_BASE1.SchDoc]
2023-03-15 refactor: PCB designer change
    PCB designer change
    [OECU_BASE.PrjPcb, OECU_BASE2.SchDoc, OECU_BASE6.SchDoc]
2023-03-20 refactor: PCB design change
    finished ps and bus3b Line length design
    [OECU_BASE1.SchDoc, OECU_BASE6.SchDoc, PinMap.xlsx]
2023-03-21 refactor: PCB design change
    PCB design change
    [OECU_BASE4.SchDoc, OECU_BASE5.SchDoc, PinMap.xlsx]
2023-03-23 refactor: PCB design almost finish
    PCB design almost finish
    [OECU_BASE.PrjPcb, OECU_BASE_BOM.xlsx]
2023-03-25 fix: fix the wrong inductance parameter
    22uh -> 2.2uh
    [OECU_BASE.xlsx, OECU_BASE3.SchDoc, OECU_BASE4.SchDoc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]
2023-04-11 refactor: update 3D model
    update 3D model
    [Column_M3x11.SLDPRT, Column_M3x16.SLDPRT, OECU_BASE.xlsx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]
2023-04-12 fix: fix a pcb bug
    fix a pcb bug
    [OECU_BASE.xlsx, OECU_BASE3.SchDoc, OECU_BASE4.SchDoc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]
2023-04-19 new: update 3d model design
    update 3d model design
    [Bolt_M3x6.SLDPRT, Column_M3x16.SLDPRT, Column_M3x6.SLDPRT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]
2023-04-20 design: 3d model design update
    3d model design update
    [外壳_上壳.SLDPRT]
2023-04-22 design: finish 3D model design
    finish 3D model design
    [外壳_上壳.SLDPRT, 外壳_上壳.STL, 外壳_底壳.SLDPRT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]
2023-04-26 fix: fix some 3D model bugs
    1.fix some 3D model bugs
    2.update readme
    [外壳_上壳.SLDPRT, 外壳_上壳.STL, 外壳_底壳.SLDPRT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]
2023-05-06 refactor：debug with vivado
    debug with vivado
2023-05-16 fix: fix a PCB bug
    1.fix a PCB bug
    [OECU_BASE.PrjPcb, OECU_BASE.xlsx, OECU_BASE2.SchDoc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]
2023-05-21 fix: change the RSET res from 4.7K to 2.49K
    change the RSET res from 4.7K to 2.49K
    [OECU_BASE.PrjPcb, OECU_BASE.xlsx, OECU_BASE2.SchDoc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]
2023-06-24 refactor: update BOM for PCB
    [OECU_BASE.PrjPcb, OECU_BASE.xlsx]
2023-07-12 feat: compute tower design
    compute tower design
    [丝杠M4_250.SLDPRT, 交换机.SLDPRT, 配电底壳.SLDPRT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]
2023-07-14 design update: compute tower 3d model
    compute tower 3d model
    [WingNutM4.SLDPRT, locknutM4.SLDPRT, 交换机.SLDPRT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]
